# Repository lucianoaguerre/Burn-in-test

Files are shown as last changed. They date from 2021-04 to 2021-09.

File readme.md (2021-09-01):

# Proyecto

Burn-in Test

## Descripcion

En este documento se propone un sistema para hacer el burn-in test a fuentes de alimentación de tipo switching de 12V x 2A. El ensayo consiste en verificar que la fuente de alimentación esté funcionando correctamente, monitoreando la salida de 12V en vacío y en carga durante un lapso de tiempo. En dicho lapso la regulación de tensión no debe ser mayor que 10%, o el criterio que se elija. 

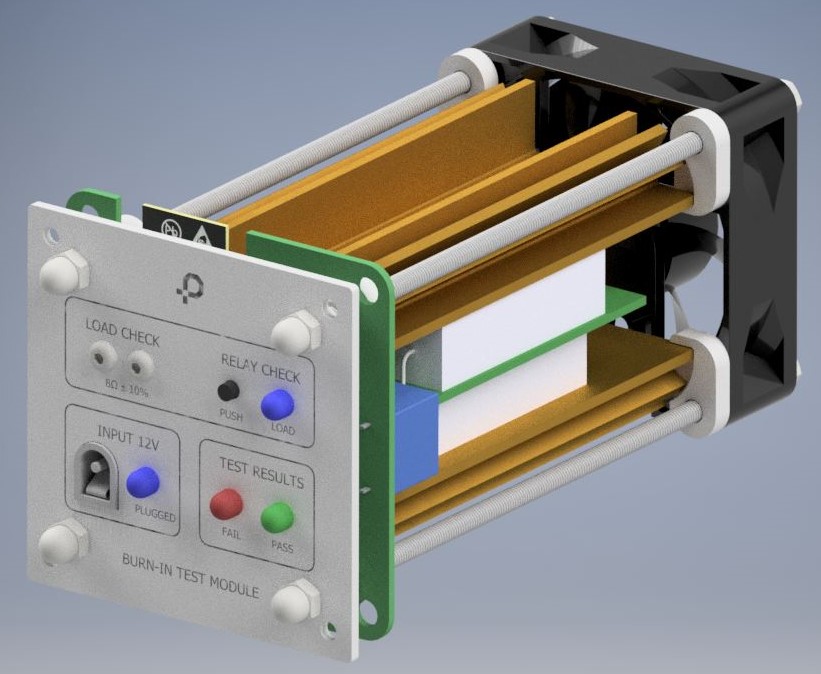
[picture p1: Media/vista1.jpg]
equipo

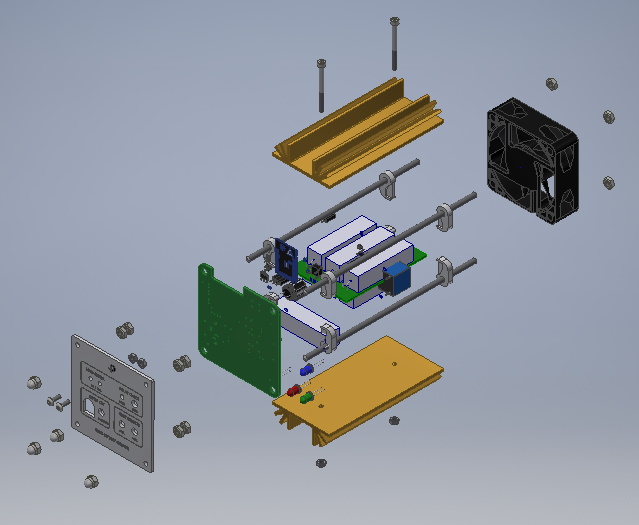
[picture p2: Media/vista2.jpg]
despiece


### Ciclado de la salida
Para estresar aún más las fuentes de alimentación que se están probando, la salida se enciende y apaga repetidamente. Si un dispositivo está destinado a fallar, generalmente pasa cuando la salida se cicla. Para capturar datos de falla, se mide la tensión de salida de cada fuente de alimentación cuando se enciende la salida. Después de que la salida se cicla de 15 a 20 veces, se deja encendida y se deja seguir envejeciendo la fuente. Mientras que la salida se deja encendida, el voltaje se mide solo ocasionalmente. 

### Ruido ambiente
Medir con exactitud la tensión de salida de una fuente switching es uy difícil en un contexto donde hay varias colocadas y funcionando al mismo tiempo, porque irradian ruido de alta frecuencia. Por lo tanto es importante que el circuito de medición realice promedios de cada muestra y tenga en cuento el efecto de sincronización de la medición de las fuentes.

### Vida útil de los componentes
Para hacer este test con carga, generalmente se utilizan relés, que conectan la resistencia con la salida de la fuente de alimentación. Pero como la fuente está encendida los relés se abren y cierran con voltaje en sus contactos. La activación de un relé de esta manera aumenta la posibilidad de formación de arco, lo que afecta la vida útil del mismo. Por otro lado, las resistencias cerámicas trabajan con una temperatura elevada, haciendo que irradien calor, debe monitorearse que la temperatura del módulo no sea muy elevada, para no reducir la vida útil de las mismas. Finalmente otro elemento que puede desgastarse es el conector de la fuente, de tanto colocar y retirar los enchufes puede dañarse las partes internas del conector y debe ser reemplazado.

### Corriente de carga
Si bien la fuente de alimentación a ensayar es de 2A, se propone que el ensayo con carga se haga al 80% de la corriente máxima, para no disipar tanto calor en los componentes.

### Ciclos
Para reducir el ruido eléctrico provocado por la transición de conexión y desconexión de las resistencias de carga, se propone un esquema de 12 ciclos de 5 segundos y luego se mantiene encendido con carga. El ciclo de la siguiente fuente comienza cuando termina la primera, y así sucesivamente. El ciclo completo de 10 fuentes es de 10 minutos. Por lo general, las recomendaciones para el test de burn-in sugieren probar las fuentes 4hs y si no hay fallas reducir el tiempo a 2hs. En el caso que ese tiempo sea muy largo se puede acortar o reducir los ciclos.

## Autor

Luciano Aguerre
[@luchoaguerre](https://twitter.com/luchoaguerre)

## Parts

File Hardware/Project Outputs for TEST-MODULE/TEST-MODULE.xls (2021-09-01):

Proveedor Electronica ELEMON
Presupuesto: 1204800 *** MODIFICAR CANTIDADES ***
Description | Designator | Quantity | COD. ELEMON | Cantidad | Precio | IVA | Total | IVA | Total + IVA
100NFX50V X7R 10% CER.MULT. SMD 0805 | C1, C2, C3, C5, C6 | 5 | CA3279774 | 700 | 0.01515 | 10.5% | 10.61 | 1.11 | 11.72
M7 DIODO 1A 1000V SMD-SMA (1N4007) XYG | D1 | 1 | DI1202221 | 200 | 0.01689 | 10.5% | 3.38 | 0.35 | 3.73
IDC-MA-THT-1X3-P2.54MM-L11 | P1 | 1 | CO4900906 | 15 | 0.22367 | 10.5% | 3.36 | 0.35 | 3.71
BC817-40 TRA.NPN 45V0.5A 0.25W SOT23 | Q1, Q3, Q4 | 3 | TR1723020 | 400 | 0.03377 | 10.5% | 13.51 | 1.42 | 14.93
33K 5% 0805 1/8W RES.SMD | R4 | 1 | RS3896275 | 5000 | 0.00224 | 10.5% | 11.20 | 1.18 | 12.38
5.6K 5% 0805 1/8W RES.SMD | R5 | 1 | RS3896230 | 5000 | 0.00224 | 10.5% | 11.20 | 1.18 | 12.38
1K 5% 0805 1/8W RES.SMD | R7 | 1 | RS3896185 | 5000 | 0.00224 | 10.5% | 11.20 | 1.18 | 12.38
220E 5% 0805 1/8W RES.SMD | R10, R12, R13, R14 | 4 | RS3896145 | 5000 | 0.00224 | 10.5% | 11.20 | 1.18 | 12.38
Relay simple inversor 12V 12A SRA-12VDC-CL | RELE | 1 | RE4551790 | 120 | 0.38998 | 21.0% | 46.80 | 9.83 | 56.63
TACT-SWITCH-THT-4C-06X06(5MM) | SW1 | 1 | SW5702101 | 120 | 0.08135 | 10.5% | 9.76 | 1.03 | 10.79
ESP32-WROOM-32E | U1 | 1 | RF9301435 | 120 | 4.48199 | 10.5% | 537.84 | 56.47 | 594.31
LD1117S33TR SMD DPAK 0.8A 3.3V LDO LINEAR REGULATOR | U2 | 1 | CI2707214DT | 120 | 0.12299 | 10.5% | 14.76 | 1.55 | 16.31
 |  |  |  |  |  |  | USD 684.80325 | USD 76.81808925 | USD 761.6213393
 |  |  |  |  |  |  | Tipo cambio BNA |  | 100.75
 |  |  |  |  |  |  |  | TOTAL | $76733.34993
Proveedor SYC-Semiconductores y Componentes
Presupuesto: 30355
Description | Designator | Quantity | COD. SYC | Cantidad | Precio | IVA | Total | IVA | Total + IVA
Transistor MOSFET N IRFD110 | Q2 | 1 | IRFD110 | 120 | 0.650 | 10.5% | 78.00 | 8.19 | 86.19
LED 5MM VERDE ALTO 9 | LD1 | 1 | LG3330 | 120 | 0.080 | 10.5% | 9.60 | 1.01 | 10.61
LED 5MM ROJO ALTO 9 | LD2 | 1 | LH3330 | 120 | 0.070 | 10.5% | 8.40 | 0.88 | 9.28
LED 5MM AZUL ALTO 9 | LD3, LD4 | 2 | LB3330 | 240 | 0.100 | 10.5% | 24.00 | 2.52 | 26.52
TACT-SWITCH-THT-4C-06X06(17MM) | SW2 | 1 | TS-6 | 30 | 0.170 | 10.5% | 5.10 | 0.54 | 5.64
10K 5% 0805 1/8W RES.SMD - pack por 100 | R1, R6, R8, R9, R11 | 5 | CR0850-10k | 6 | 0.500 | 10.5% | 3.00 | 0.32 | 3.31
 |  |  |  |  |  |  | USD 128.1 | USD 13.4505 | USD 141.5505
 |  |  |  |  |  |  | Tipo Cambio ICBC |  | 101.5
 |  |  |  |  |  |  |  | TOTAL | $14367.37575
Proveedor Microelectronica SH
Presupuesto: V 0001-00008601
Description | Designator | Quantity | COD. MicroelectronicaSH | Cantidad | Precio | IVA | Total | IVA | Total + IVA
DC POWER JACK VERTICAL 2MM | P3 | 1 | Jk-dc021-vert | 120 | 54.11 | 21.0% | 6492.96 | 1363.52 | 7856.48
100UFX16V 20%. 6.3x5.3 ELE.RAD.SMD [R=] | C4 | 1 | Ce100x16smd | 120 | 16.50 | 21.0% | 1980.00 | 415.80 | 2395.80
Resistencia Ceramica 330E 5% 10W SE15 RES.CEM | R2, R3 | 2 | RA-10W-330 | 240 | 50.79 | 21.0% | 12189.36 | 2559.77 | 14749.13
TACT-SWITCH-THT-4C-06X06(17MM) | SW2 | 1 | TS4-17 | 120 | 23.84 | 10.5% | 2860.80 | 300.38 | 3161.18
 |  |  |  |  |  |  | $23523.12 | $4639.4712 | $28162.5912
 |  |  |  |  |  |  |  | TOTAL | $28162.5912
Proveedor Ernesto Mayer
Presupuesto: 231456.1
Description | Designator | Quantity |  | Cantidad | Precio | IVA | Total | IVA | Total + IVA
Test Module |  | 120 |  | 120 | 5.79 | 10.5% | 694.80 | 72.95 | 767.75
Gasto de prefabricacion |  | 1 |  | 1 | 30.00 | 21.0% | 30.00 | 6.30 | 36.30
 |  |  |  |  |  |  | USD 724.8 | USD 79.254 | USD 804.054
 |  |  |  |  |  |  | Tipo cambio BNA |  | 101.25
 |  |  |  |  |  |  |  | TOTAL | $81410.4675
Proveedor Abul Tornillos
Presupuesto:
Description | Designator | Quantity |  | Cantidad | Precio | IVA | Total | IVA | Total + IVA
TORNILLO ISO 7380-1 - M3x16 |  | 4 |  | 504 | 15.00 | 21.0% | 7560.00 | 1587.60 | 9147.60
TUERCA DIN 934 M3x0.5 |  | 4 |  | 504 | 4.00 | 21.0% | 2016.00 | 423.36 | 2439.36
 |  |  |  |  |  |  | $9576 | $2010.96 | $11586.96
 |  |  |  |  |  |  |  | TOTAL | $11586.96
Proveedor Wabe 3D
Presupuesto:
Description | Designator | Quantity |  | Cantidad | Precio | IVA | Total | IVA | Total + IVA
Frente |  | 4 |  | 504 | 15.00 | 21.0% | 7560.00 | 1587.60 | 9147.60
Separador para placa |  | 4 |  | 504 | 10.00 | 21.0% | 5040.00 | 1058.40 | 6098.40
Separador para LED |  | 4 |  | 504 | 10.00 | 21.0% | 5040.00 | 1058.40 | 6098.40
 |  |  |  |  |  |  | $17640 | $3704.4 | $21344.4
 |  |  |  |  |  |  |  | TOTAL | $21344.4
 |  |  |  |  |  |  |  | Total | $233605.1444

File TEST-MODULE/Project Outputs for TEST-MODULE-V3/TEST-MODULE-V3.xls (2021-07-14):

Description | Designator | Quantity | COD. ELEMON | Total
100NFX50V X7R 10% CER.MULT. SMD 0805 | C1, C2, C3, C5, C6 | 5 | CA3279774 | 600
470UFX25V 85°C 10x13 ELE.RAD | C4 | 1 | CA3609281A | 120
Diodo 1N4007 DIODO 1A 1000V DO41 | D1 | 1 | DI1152060 | 120
IDC-HE-THT-1X4-P2.54MM | P1 | 1 | CO5001085 | 120
IDC-MA-THT-1X2-P2.54MM-L11 | P2 | 1 | CO496C20 | 120
BC817-40 TRA.NPN 45V0.5A 0.25W SOT23 | Q2, Q3, Q4 | 3 | TR1723020 | 360
10K 5% 0805 1/8W RES.SMD | R1, R6, R8, R13, R16 | 5 | RS3896245 | 600
220E 5% 0805 1/8W RES.SMD | R3, R4, R5, R7 | 4 | RS3896145 | 480
33K 5% 0805 1/8W RES.SMD | R9 | 1 | RS3896275 | 120
5.6K 5% 0805 1/8W RES.SMD | R10 | 1 | RS3896230 | 120
Resistencia Ceramica 330E 5% 10W SE15 RES.CEM | R11, R12 | 2 | RS4096155 | 240
1K 5% 0805 1/8W RES.SMD | R14 | 1 | RS3896185 | 120
Relay simple inversor 12V 12A | RELE1 | 1 | RE4551790 | 120
TACT-SWITCH-THT-4C-06X06(13MM)-JIANFU | SW1 | 1 | SW5702124 | 120
TACT-SWITCH-THT-4C-06X06(5MM) | SW2 | 1 | SW5702101 | 120
ESP32-WROOM-32D | U1 | 1 | RF9301435 | 120
LD1117S33TR SMD DPAK 0.8A 3.3V LDO LINEAR REGULATOR | U2 | 1 | CI2707214DT | 120
LED 5MM AZUL ALTO 9 | LD1, LD4 | 2 |  | 240
LED 5MM VERDE ALTO 9 | LD2 | 1 |  | 120
LED 5MM ROJO ALTO 9 | LD3 | 1 |  | 120
DC POWER JACK VERTICAL 2MM | P4 | 1 |  | 120
Transistor MOSFET N IRFD110 | Q1 | 1 |  | 120

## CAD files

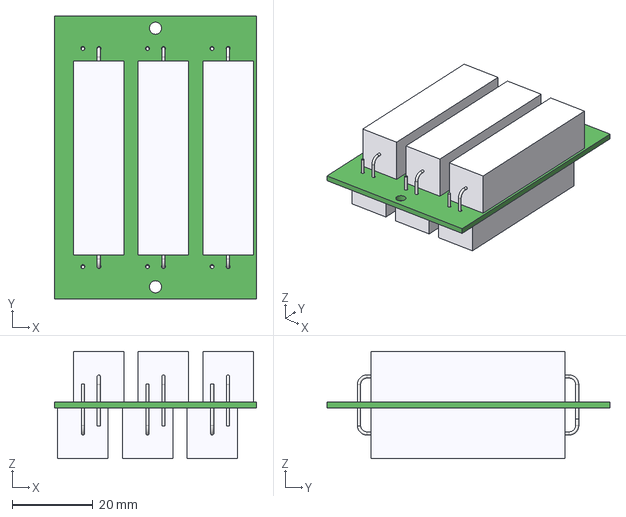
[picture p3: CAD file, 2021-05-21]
TEST-MODULE/3D/RESISTOR-BOARD/RESISTORS-BOARD.step
50.0 x 70.0 x 26.6 mm
Board
AXIAL-POWER x 6

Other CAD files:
Hardware/3D/AXIAL-POWER-10W.ipt
Hardware/3D/Board.ipt
Hardware/3D/C1.iam
Hardware/3D/C2.iam
Hardware/3D/C3.iam
Hardware/3D/C4.iam
Hardware/3D/C5.iam
Hardware/3D/C6.iam
Hardware/3D/CAP-ELEC-SMD-100UF.ipt
Hardware/3D/CAP-SMD-0805.iam
Hardware/3D/CON-PIN-CORTO.ipt
Hardware/3D/D1.iam
Hardware/3D/DC-JACK-VERT.ipt
Hardware/3D/DPAK.iam
Hardware/3D/Diode_SMA.ipt
Hardware/3D/LD1.iam
Hardware/3D/LD2.iam
Hardware/3D/LD3.iam
Hardware/3D/LD4.iam
Hardware/3D/LED_5MM_BLUE_9.ipt
Hardware/3D/LED_5MM_GREEN_9.ipt
Hardware/3D/LED_5MM_RED_9.ipt
Hardware/3D/OldVersions/TEST-MODULE.0001.iam
Hardware/3D/Open CASCADE STEP translator 6.8 4.2.1.1.ipt
Hardware/3D/Open CASCADE STEP translator 6.8 4.2.1.2.ipt
Hardware/3D/Open CASCADE STEP translator 6.8 4.2.1.3.ipt
Hardware/3D/Open CASCADE STEP translator 6.8 4.2.1.4.ipt
Hardware/3D/Open CASCADE STEP translator 6.8 4.38.1.1.ipt
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

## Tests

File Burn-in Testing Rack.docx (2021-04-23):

Burn-in Testing

Introducción

En este documento se propone un sistema para hacer el burn-in test a fuentes de alimentación de tipo switching de 12V x 2A. El ensayo consiste en verificar que la fuente de alimentación esté funcionando correctamente, monitoreando la salida de 12V en vacío y en carga durante un lapso de tiempo. En dicho lapso la regulación de tensión no debe ser mayor que 10%, o el criterio que se elija.

Monitoreo de Tensión

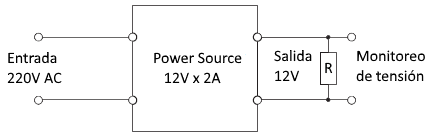
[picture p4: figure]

La figura 1 es un esquema simple de una prueba para monitorear la salida de tensión de una fuente de alimentación. Un sistema de conversión analógico digital se conectaría en paralelo con la resistencia de carga para medir el voltaje de la fuente de alimentación.

Figura 1. Monitoreo de tensión

El valor de la resistencia de carga se elige simulando la carga encontrada en la aplicación final, pero también puede elegirse para alcanzar la máxima capacidad de salida haciendo una prueba de esfuerzo de la fuente.

Ciclado de la salida

Para estresar aún más las fuentes de alimentación que se están probando, la salida se enciende y apaga repetidamente. Si un dispositivo está destinado a fallar, generalmente pasa cuando la salida se cicla. Para capturar datos de falla, se mide la tensión de salida de cada fuente de alimentación cuando se enciende la salida, como se muestra en la Figura 2. Después de que la salida se cicla de 15 a 20 veces, se deja encendida y se deja seguir envejeciendo la fuente. Mientras que la salida se deja encendida, el voltaje se mide solo ocasionalmente.

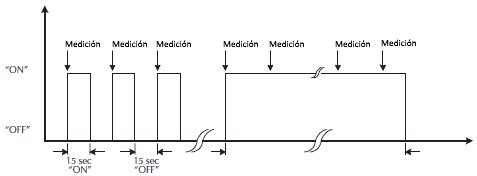
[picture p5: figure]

Figura 2. Ciclo típico de burn-in test.

Ruido ambiente

Medir con exactitud la tensión de salida de una fuente switching es uy difícil en un contexto donde hay varias colocadas y funcionando al mismo tiempo, porque irradian ruido de alta frecuencia. Por lo tanto es importante que el circuito de medición realice promedios de cada muestra y tenga en cuento el efecto de sincronización de la medición de las fuentes.

Vida útil de los componentes

Para hacer este test con carga, generalmente se utilizan relés, que conectan la resistencia con la salida de la fuente de alimentación. Pero como la fuente está encendida los relés se abren y cierran con voltaje en sus contactos. La activación de un relé de esta manera aumenta la posibilidad de formación de arco, lo que afecta la vida útil del mismo. Por otro lado, las resistencias cerámicas trabajan con una temperatura elevada, haciendo que irradien calor, debe monitorearse que la temperatura del módulo no sea muy elevada, para no reducir la vida útil de las mismas. Finalmente otro elemento que puede desgastarse es el conector de la fuente, de tanto colocar y retirar los enchufes puede dañarse las partes internas del conector y debe ser reemplazado.

Corriente de carga

Si bien la fuente de alimentación a ensayar es de 2A, se propone que el ensayo con carga se haga al 80% de la corriente máxima, para no disipar tanto calor en los componentes.

Implementación del sistema

Módulos

Dadas las consideraciones expuestas anteriormente se propone que el sistema de medición, ilustrado en la figura 3, conste de un módulo central, donde están los procesadores con los conversores AD, y de 10 módulos de carga donde están los componentes que pueden fallar. Todos interconectados con cables para que sea sencillo el reemplazo de un módulo por otro, en el caso de que un componente falle.

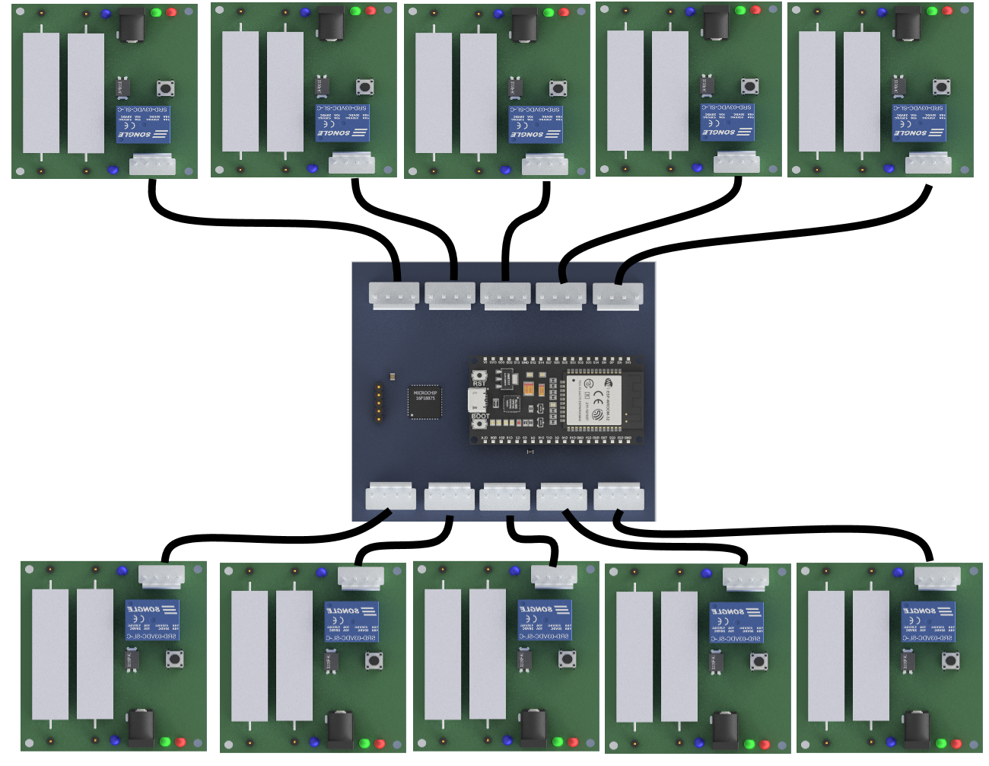
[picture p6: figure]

Figura 3. Ilustración de sistema de medición

Ciclos

Para reducir el ruido eléctrico provocado por la transición de conexión y desconexión de las resistencias de carga, se propone un esquema de 12 ciclos de 5 segundos y luego se mantiene encendido con carga. El ciclo de la siguiente fuente comienza cuando termina la primera, y así sucesivamente. El ciclo completo de 10 fuentes es de 10 minutos. Por lo general, las recomendaciones para el test de burn-in sugieren probar las fuentes 4hs y si no hay fallas reducir el tiempo a 2hs. En el caso que ese tiempo sea muy largo se puede acortar o reducir los ciclos.

Figura 4. Esquema de ciclos de carga

Detalle módulo de carga

En la figura 5 se ve con más detalle las partes que componen el módulo de carga. El circuito está compuesto por el Jack Power donde se conecta la fuente de alimentación a ensayar, a la izquierda está los dos LEDs indicadores de aceptado o rechazado. En la parte inferior están las dos resistencias de carga de 15 ohm x 15W, que toman 1.6A de la fuente, es decir el 80% de la máxima como se había propuesto. El LED azul de la izquierda es un testigo de que la fuente está enchufada correctamente, y el LED azul de la derecha es un testigo de que hay tensión después del relé. A ambos lados de las resistencias hay pines de prueba, para verificar que después de un periodo de tiempo mantiene su valor nominal. El pulsador provoca un disparo del relé, con el fin de verificar que el mismo funcione correctamente.

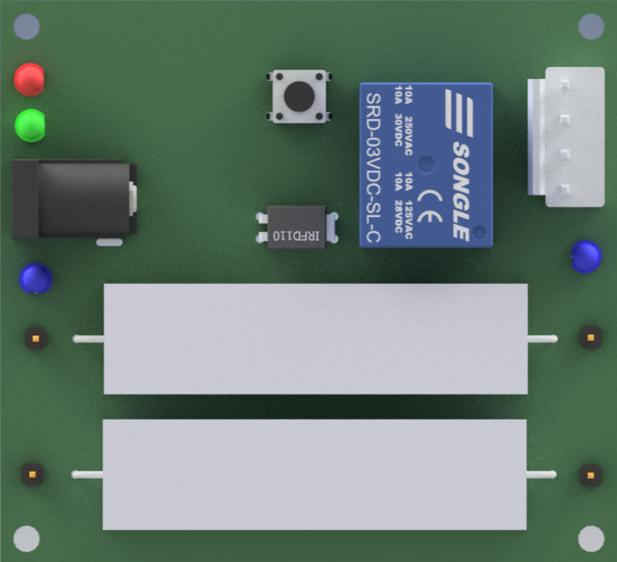
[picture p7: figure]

Figura 5. Módulo de carga

Antes de empezar con los ensayos a un lote fuentes se debe medir con un multímetro que los valores de las resistencias estén dentro los parámetros admisibles, para ello se conectan las puntas en los pines dispuestos para tal ensayo, el valor medido debería ser 7,5 ohms con una tolerancia del 20%. Del mismo modo, debe procederse al finalizar la jornada. También se debe verificar que el relé no se haya dañado, para ello se puede utilizar el pulsador dispuesto en la placa, que energiza al relé haciendo que pase tensión a las resistencias. En este caso debe encenderse el LED azul dispuesto cerca del conector de datos.

Detalle módulo central

En la figura 6 se ve con más detalle las partes que componen el módulo central. El circuito está compuesto por un sub módulo de alimentación de 12V, el microcontrolador central PIC16F18875 que es el responsable de la toma de datos y el procesamiento de las señales, y un módulo ESP32, que va alojar un pequeño web server para que los datos puedan ser tomados de forma remota y por último los conectores para los módulos de carga.

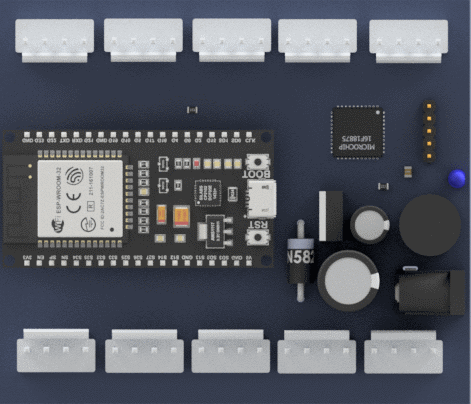
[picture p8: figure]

Figura 6. Módulo central

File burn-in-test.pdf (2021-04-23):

# Burn-in Testing

## Introducción

En este documento se propone un sistema para hacer el burn-in test a fuentes de alimentación de tipo switching de 12V x 2A. El ensayo consiste en verificar que la fuente de alimentación esté funcionando correctamente, monitoreando la salida de 12V en vacío y en carga durante un lapso de tiempo. En dicho lapso la regulación de tensión no debe ser mayor que 10%, o el criterio que se elija.

Monitoreo de Tensión
La figura 1 es un esquema simple de una prueba para monitorear la salida de tensión de una fuente de alimentación. Un sistema de conversión analógico digital se conectaría en paralelo con la resistencia de carga para medir el voltaje de la fuente de alimentación.

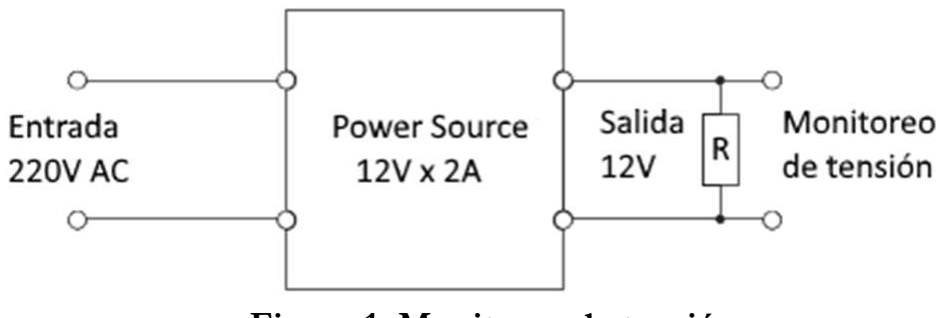
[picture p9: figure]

Figura 1. Monitoreo de tensión
El valor de la resistencia de carga se elige simulando la carga encontrada en la aplicación final, pero también puede elegirse para alcanzar la máxima capacidad de salida haciendo una prueba de esfuerzo de la fuente.

Ciclado de la salida
Para estresar aún más las fuentes de alimentación que se están probando, la salida se enciende y apaga repetidamente. Si un dispositivo está destinado a fallar, generalmente pasa cuando la salida se cicla. Para capturar datos de falla, se mide la tensión de salida de cada fuente de alimentación cuando se enciende la salida, como se muestra en la Figura 2. Después de que la salida se cicla de 15 a 20 veces, se deja encendida y se deja seguir envejeciendo la fuente. Mientras que la salida se deja encendida, el voltaje se mide solo ocasionalmente.

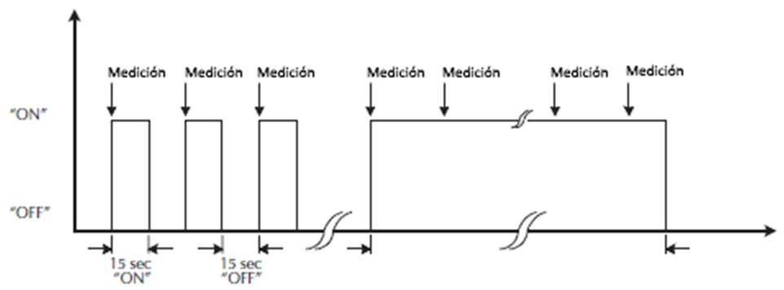
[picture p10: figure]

Figura 2. Ciclo típico de burn-in test.

Ruido ambiente
Medir con exactitud la tensión de salida de una fuente switching es uy difícil en un contexto donde hay varias colocadas y funcionando al mismo tiempo, porque irradian ruido de alta frecuencia. Por lo tanto es importante que el circuito de medición realice promedios de cada muestra y tenga en cuento el efecto de sincronización de la medición de las fuentes.

Vida útil de los componentes
Para hacer este test con carga, generalmente se utilizan relés, que conectan la resistencia con la salida de la fuente de alimentación. Pero como la fuente está encendida los relés se abren y cierran con voltaje en sus contactos. La activación de un relé de esta manera aumenta la posibilidad de formación de arco, lo que afecta la vida útil del mismo. Por otro lado, las resistencias cerámicas trabajan con una temperatura elevada, haciendo que irradien calor, debe monitorearse que la temperatura del módulo no sea muy elevada, para no reducir la vida útil de las mismas. Finalmente otro elemento que puede desgastarse es el conector de la fuente, de tanto colocar y retirar los enchufes puede dañarse las partes internas del conector y debe ser reemplazado.

Corriente de carga
Si bien la fuente de alimentación a ensayar es de 2A, se propone que el ensayo con carga se haga al 80% de la corriente máxima, para no disipar tanto calor en los componentes.

## Implementación del sistema

Módulos
Dadas las consideraciones expuestas anteriormente se propone que el sistema de medición, ilustrado en la figura 3, conste de un módulo central, donde están los procesadores con los conversores AD, y de 10 módulos de carga donde están los componentes que pueden fallar. Todos interconectados con cables para que sea sencillo el reemplazo de un módulo por otro, en el caso de que un componente falle.

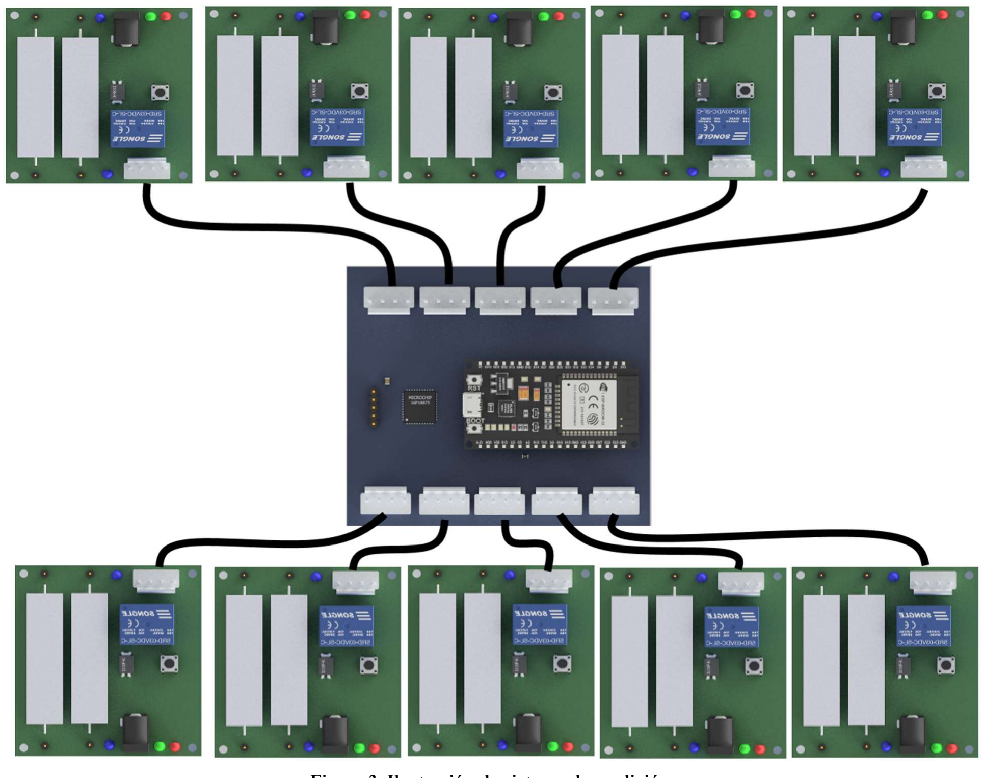
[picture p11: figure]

Figura 3. Ilustración de sistema de medición

Ciclos
Para reducir el ruido eléctrico provocado por la transición de conexión y desconexión de las resistencias de carga, se propone un esquema de 12 ciclos de 5 segundos y luego se mantiene encendido con carga. El ciclo de la siguiente fuente comienza cuando termina la primera, y así sucesivamente. El ciclo completo de 10 fuentes es de 10 minutos. Por lo general, las recomendaciones para el test de burn-in sugieren probar las fuentes 4hs y si no hay fallas reducir el tiempo a 2hs. En el caso que ese tiempo sea muy largo se puede acortar o reducir los ciclos.

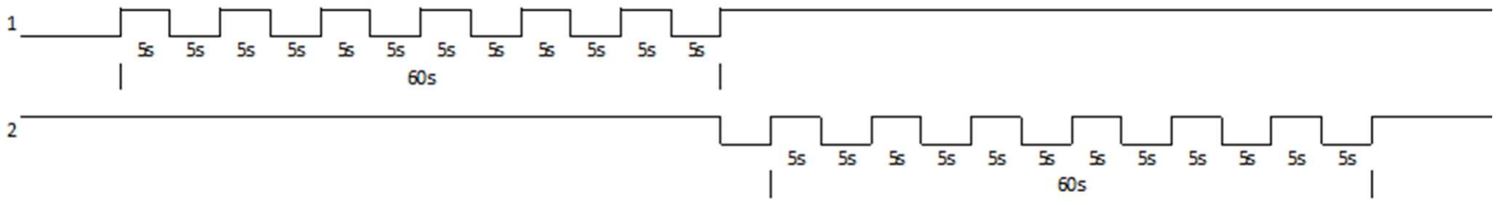
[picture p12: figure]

Figura 4. Esquema de ciclos de carga

Detalle módulo de carga
En la figura 5 se ve con más detalle las partes que componen el módulo de carga. El circuito está compuesto por el Jack Power donde se conecta la fuente de alimentación a ensayar, a la izquierda está los dos LEDs indicadores de aceptado o rechazado. En la parte inferior están las dos resistencias de carga de 15 ohm x 15W, que toman 1.6A de la fuente, es decir el 80% de la máxima como se había propuesto. El LED azul de la izquierda es un testigo de que la fuente está enchufada correctamente, y el LED azul de la derecha es un testigo de que hay tensión después del relé. A ambos lados de las resistencias hay pines de prueba, para verificar que después de un periodo de tiempo mantiene su valor nominal. El pulsador provoca un disparo del relé, con el fin de verificar que el mismo funcione correctamente.

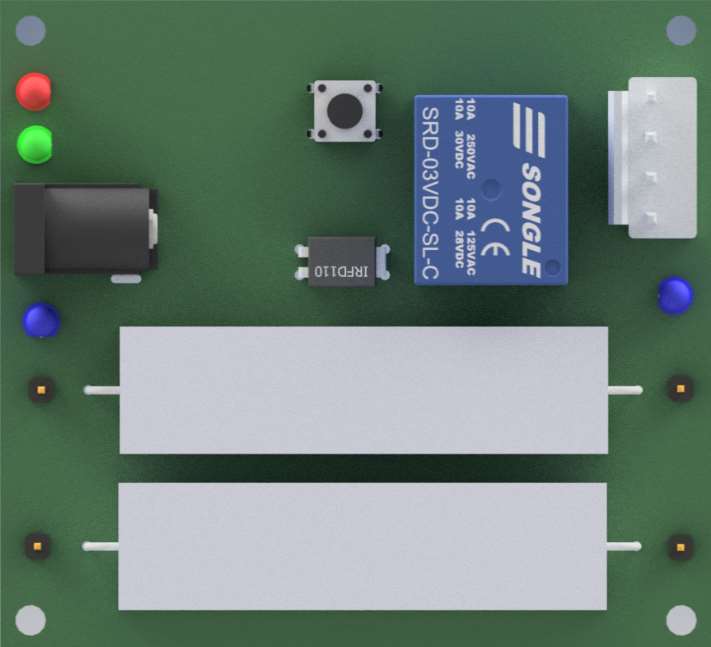
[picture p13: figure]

Figura 5. Módulo de carga

Antes de empezar con los ensayos a un lote fuentes se debe medir con un multímetro que los valores de las resistencias estén dentro los parámetros admisibles, para ello se conectan las puntas en los pines dispuestos para tal ensayo, el valor medido debería ser 7,5 ohms con una tolerancia del 20%. Del mismo modo, debe procederse al finalizar la jornada. También se debe verificar que el relé no se haya dañado, para ello se puede utilizar el pulsador dispuesto en la placa, que energiza al relé haciendo que pase tensión a las resistencias. En este caso debe encenderse el LED azul dispuesto cerca del conector de datos.

Detalle módulo central
En la figura 6 se ve con más detalle las partes que componen el módulo central. El circuito está compuesto por un sub módulo de alimentación de 12V, el microcontrolador central PIC16F18875 que es el responsable de la toma de datos y el procesamiento de las señales, y un módulo ESP32, que va alojar un pequeño web server para que los datos puedan ser tomados de forma remota y por último los conectores para los módulos de carga.


Figura 6. Módulo central

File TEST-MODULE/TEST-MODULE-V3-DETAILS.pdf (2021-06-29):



Comment | Description | Designator | Footprint | LibRef | Quantity | COD. ELEMON | COD. SYC
100NFX50V | 100NFX50V X7R 10% CER.MULT. SMD 0805 | C1, C2, C3, C5, C6 | CAP.SMD.0805 | Capacitor 100NFX50V X7R 10% CER.MULT. SMD 0805 | 5 | CA3279774

470UFX25V | 470UFX25V 85°C 10x13 ELE.RAD | C4 | CAP-ELEC-10X13 | Capacitor Electrolitico 470UFX25V 85°C 10x13 ELE.RAD | 1 | CA3609281A

1N4007 | Diodo 1N4007 DIODO 1A 1000V DO41 | D1 | Diode DO41 | Diodo 1N4007 DIODO 1A 1000V DO41 | 1 | DI1152060

LED 5MM AZUL | LED 5MM AZUL ALTO 9 | LD1, LD4 | LED-5MM-ALTO-9-AZUL | LED 5MM AZUL ALTO 9 | 2

LED 5MM VERDE | LED 5MM VERDE ALTO 9 | LD2 | LED-5MM-ALTO-9-VERDE | LED 5MM VERDE ALTO 9 | 1

LED 5MM ROJO | LED 5MM ROJO ALTO 9 | LD3 | LED-5MM-ALTO-9-ROJO | LED 5MM ROJO ALTO 9 | 1

IDC-HE-THT-1X4-P2.54MM | IDC-HE-THT-1X4-P2.54MM | P1 | IDC-HE-THT-1X4-P2.54MM | IDC-HE-THT-1X4-P2.54MM | 1 | CO5001085 | PB04S

IDC-MA-THT-1X2-P2.54MM-L11 | IDC-MA-THT-1X2-P2.54MM-L11 | P2 | IDC-MA-THT-1X2-P2.54MM-L11 | IDC-MA-THT-1X2-P2.54MM-L11 | 1 | CO496C20

DC POWER JACK | DC POWER JACK VERTICAL 2MM | P4 | VAR-DC-JACK -VERT | DC POWER JACK VERTICAL 2MM | 1

IRFD110 | Transistor MOSFET N IRFD110 | Q1 | TRA-IRFD110 | Transistor MOSFET N IRFD110 | 1

BC817 | BC817-40 TRA.NPN 45V0.5A 0.25W SOT23 | Q2, Q3, Q4 | NPN.SMD.SOT23 | Transistor BC817-40 TRA.NPN 45V0.5A 0.25W SOT23 | 3 | TR1723020

10K | 10K 5% 0805 1/8W RES.SMD | R1, R6, R8, R13, R16 | RES.SMD.103 | Resistencia 10K 5% 0805 1/8W | 5 | RS3896245

220E | 220E 5% 0805 1/8W RES.SMD | R3, R5, R7 | RES.SMD.221 | Resistencia 220E 5% 0805 1/8W | 3 | RS3896145

220E 5% | 220E 5% 0805 1/8W RES.SMD | R4 | RES.SMD.221 | Resistencia 220E 5% 0805 1/8W | 1 | RS3896145

33K | 33K 5% 0805 1/8W RES.SMD | R9 | RES.SMD.333 | Resistencia 33K 5% 0805 1/8W | 1 | RS3896275

5.6K | 5.6K 5% 0805 1/8W RES.SMD | R10 | RES.SMD.562 | Resistencia 5.6K 5% 0805 1/8W | 1 | RS3896230

330E 5% 10W | Resistencia Ceramica 330E 5% 10W SE15 RES.CEM | R11, R12 | RES-CERAMICA-10W | Resistencia Ceramica 330E 5% 10W SE15 RES.CEM | 2 | RS4096155

1K | 1K 5% 0805 1/8W RES.SMD | R14 | RES.SMD.102 | Resistencia 1K 5% 0805 1/8W | 1 | RS3896185

Relay simple inversor 12V 12A | Relay simple inversor 12V 12A | RELE1 | RELAY 12V 12A CHICO | VAR-RELE-12V Relay simple inversor chico 12V 12A | 1

TACT-SWITCH-THT-4C-06X06(13MM)-JIANFU | TACT-SWITCH-THT-4C-06X06(13MM)-JIANFU | SW1 | TACT-SWITCH-THT-4C-06X06-13MM | TACT-SWITCH-THT-4C-06X06(13MM)-JIANFU | 1 | SW5702124

TACT-SWITCH-THT-4C-06X06(5MM) | TACT-SWITCH-THT-4C-06X06(5MM) | SW2 | TACT-SWITCH-THT-4C-06X06-5MM | TACT-SWITCH-THT-4C-06X06(5MM) | 1 | SW5702101

ESP32-WROOM-32D | ESP32-WROOM-32D | U1 | ESP32-WROOM-32D | ESP32-WROOM-32D | 1 | RF9301435

LD1117S33TR SMD DPAK 0.8A 3.3V LDO LINEAR REGULATOR | LD1117S33TR SMD DPAK 0.8A 3.3V LDO LINEAR REGULATOR | U2 | DPAK | LD1117S33TR SMD DPAK 0.8A 3.3V LDO LINEAR REGULATOR | 1

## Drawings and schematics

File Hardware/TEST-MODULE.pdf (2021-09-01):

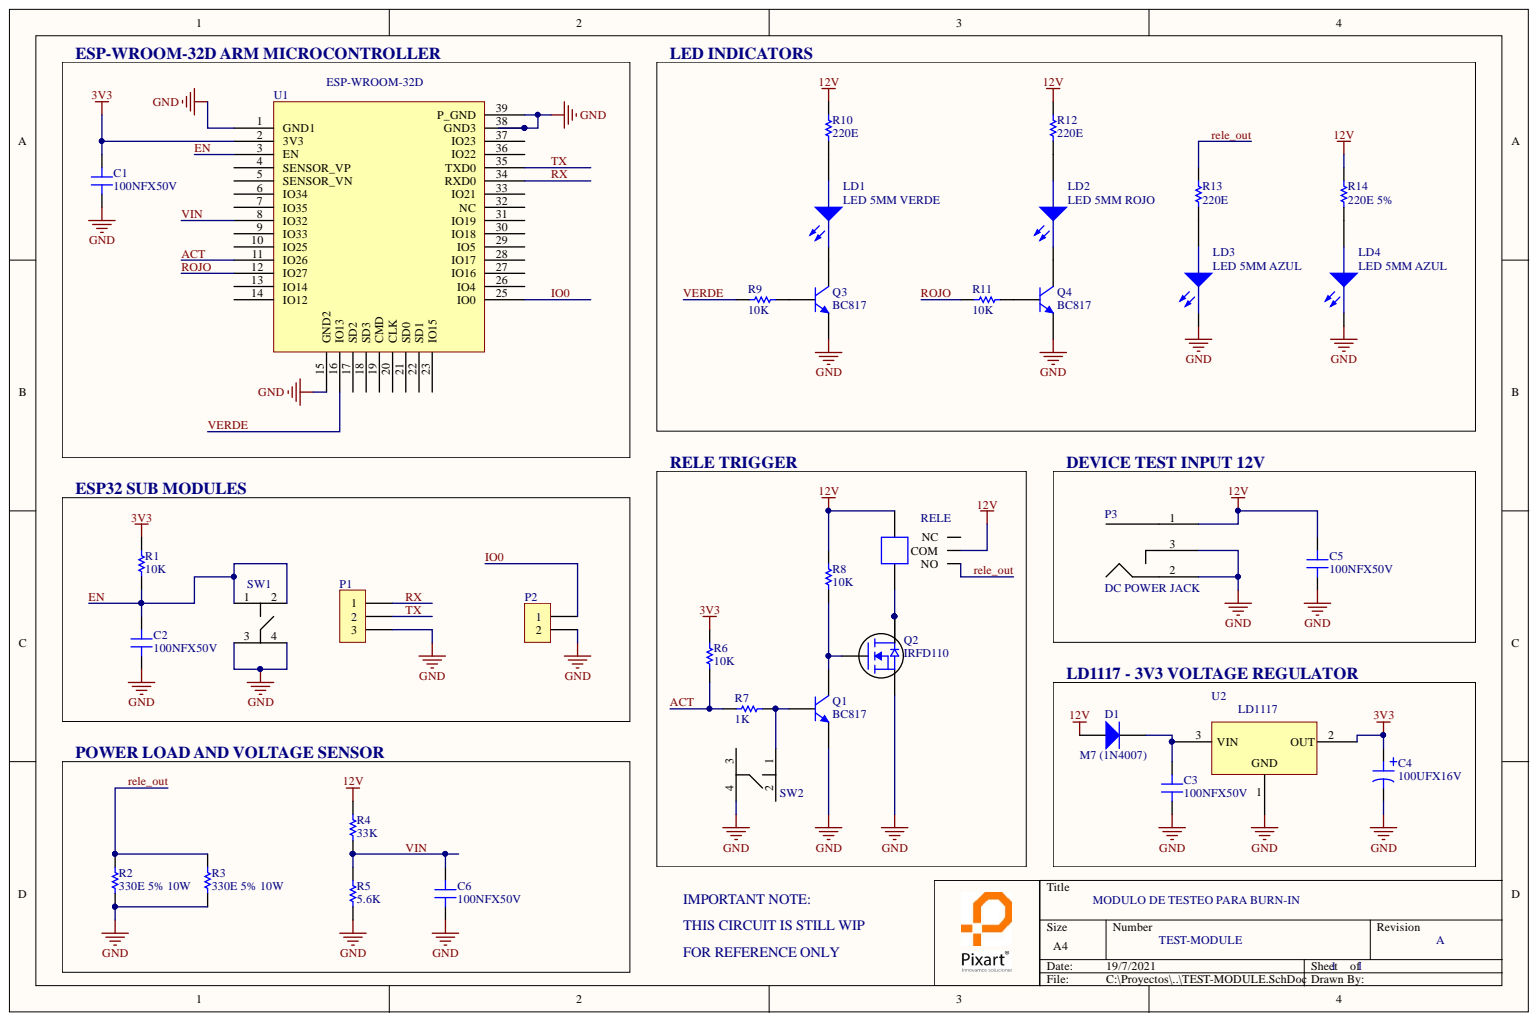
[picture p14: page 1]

THIS CIRCUIT IS STILL WIP FOR REFERENCE ONLY

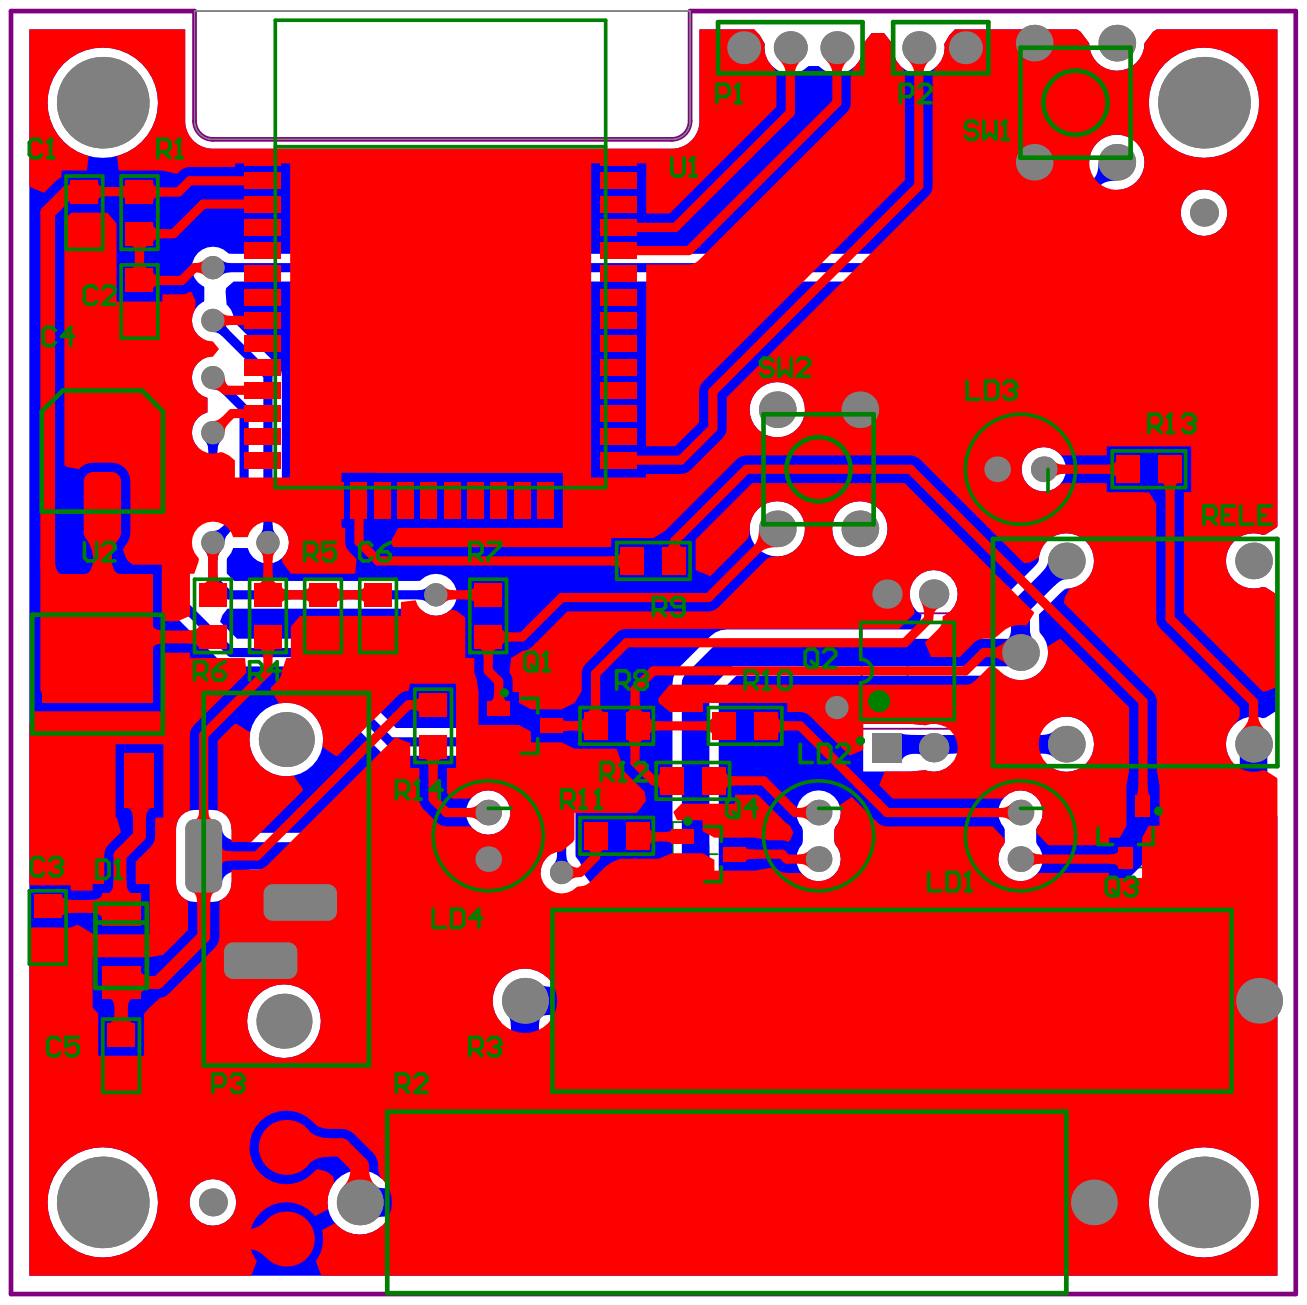
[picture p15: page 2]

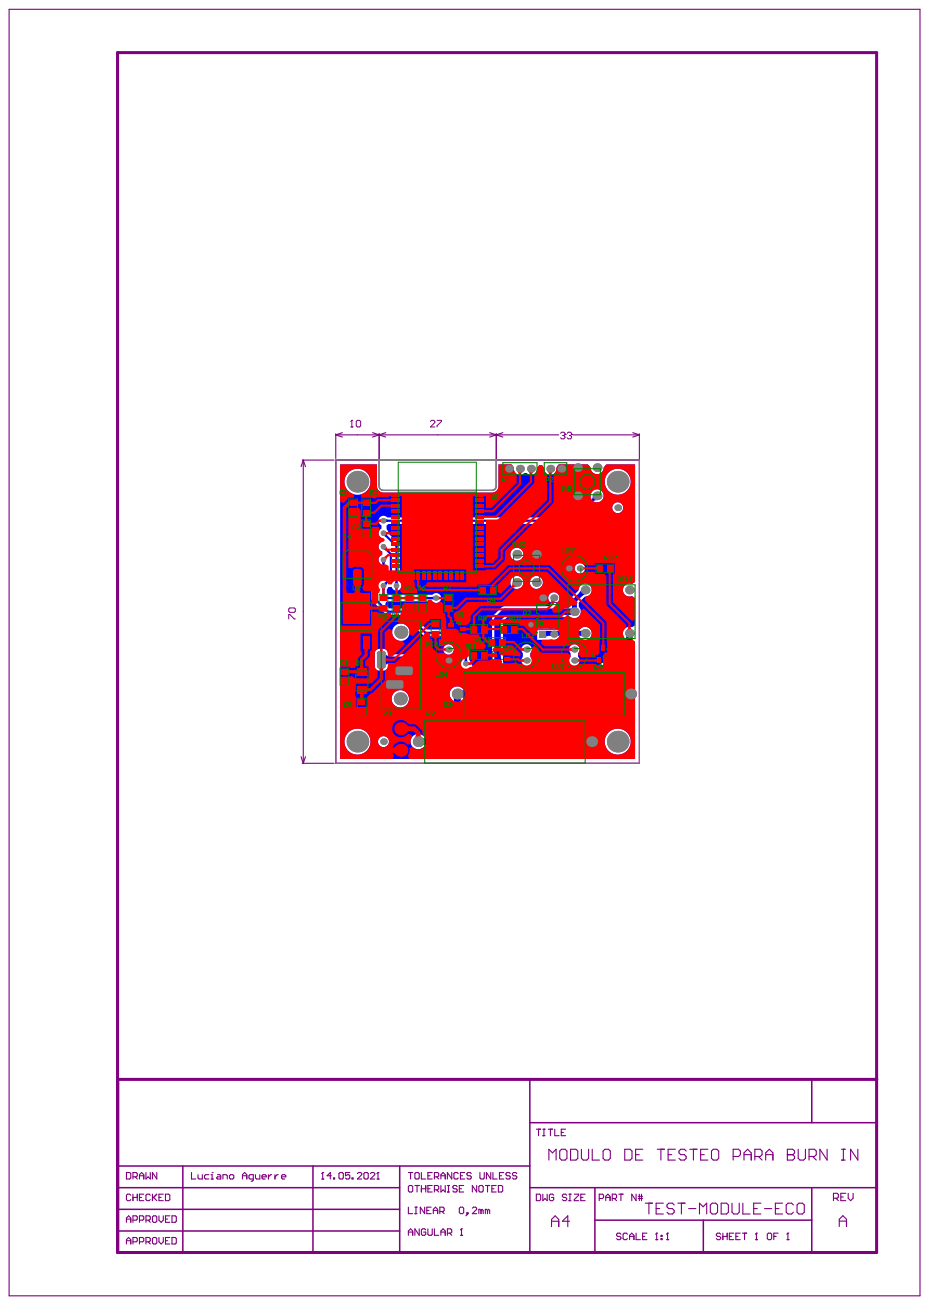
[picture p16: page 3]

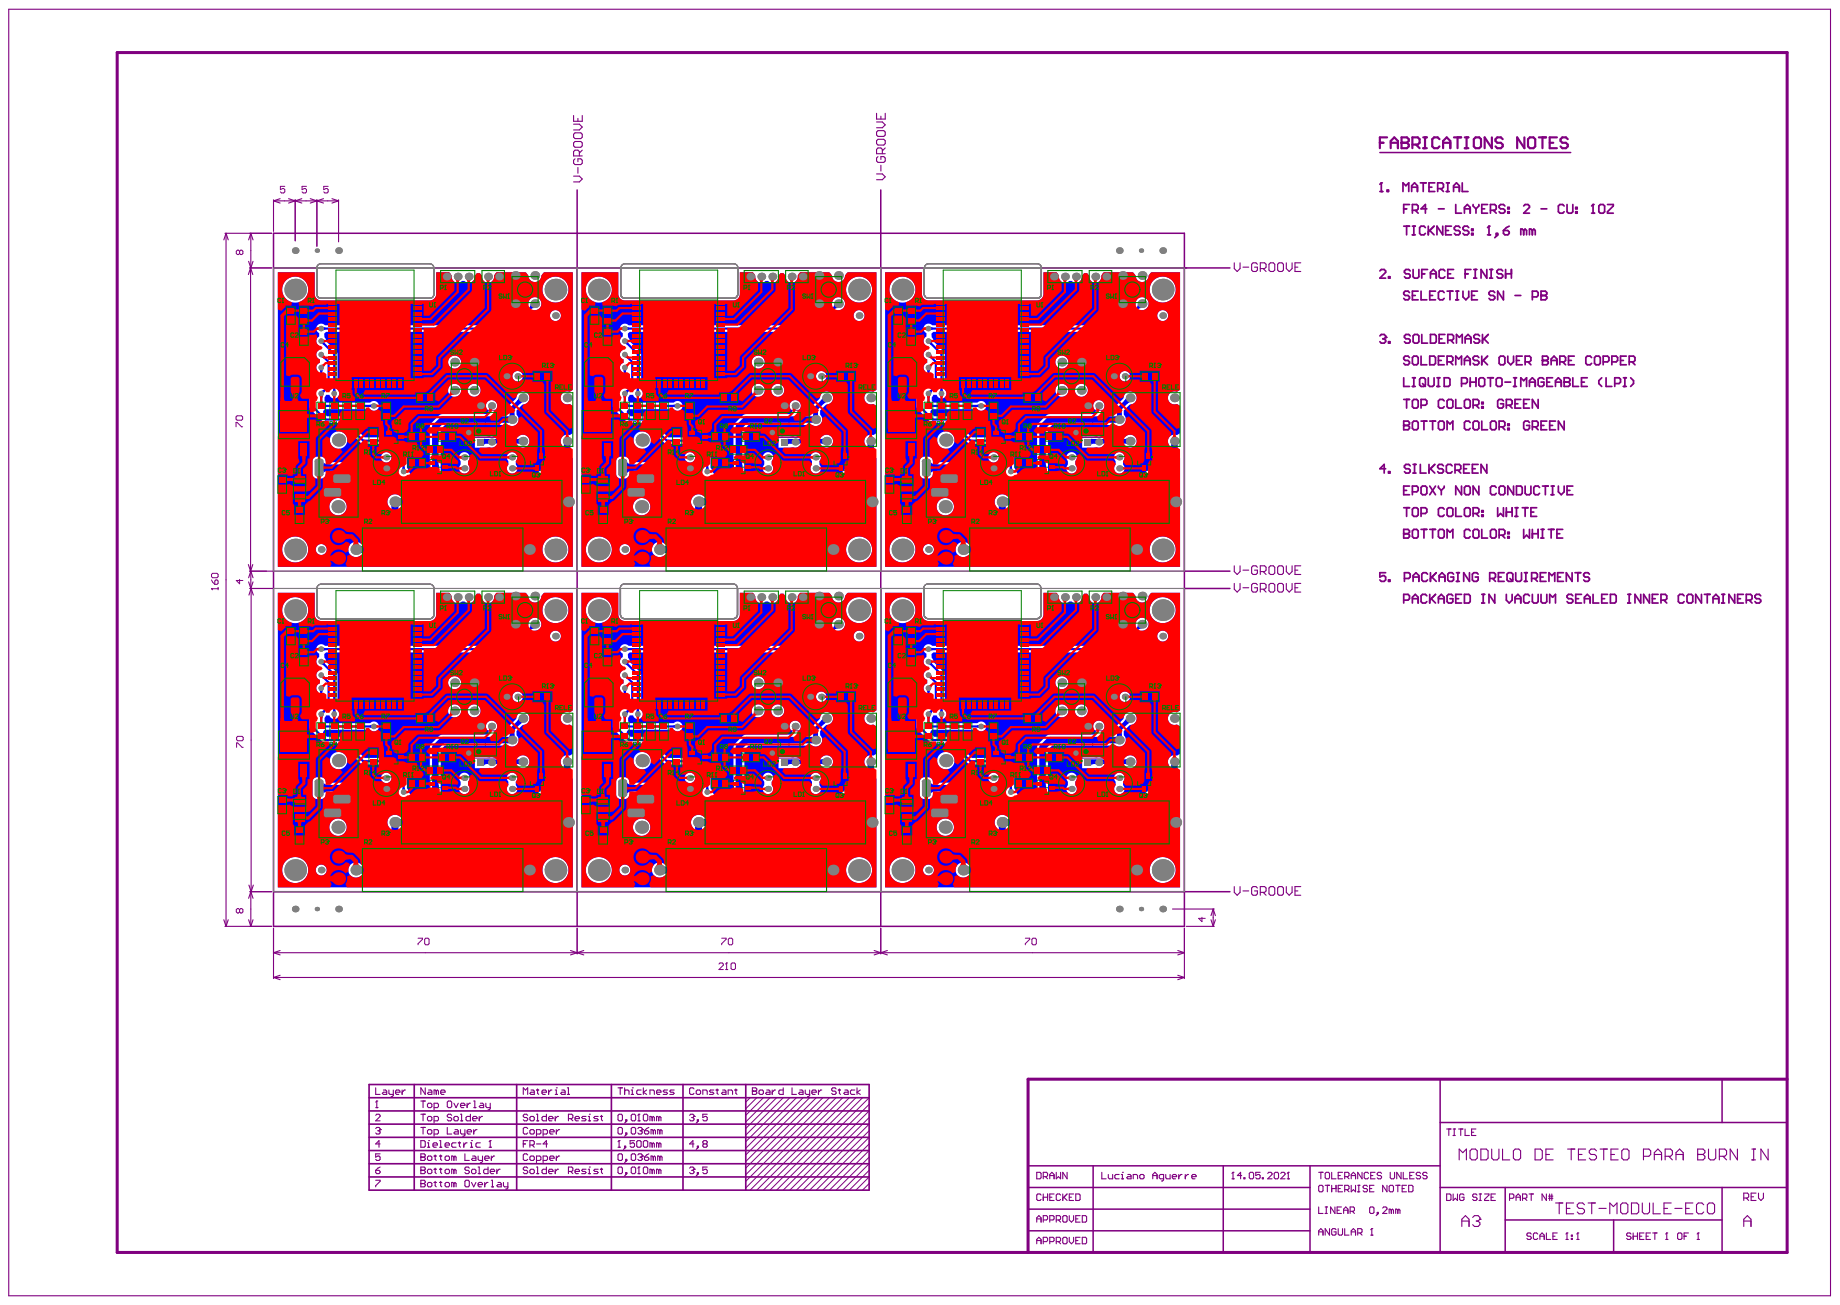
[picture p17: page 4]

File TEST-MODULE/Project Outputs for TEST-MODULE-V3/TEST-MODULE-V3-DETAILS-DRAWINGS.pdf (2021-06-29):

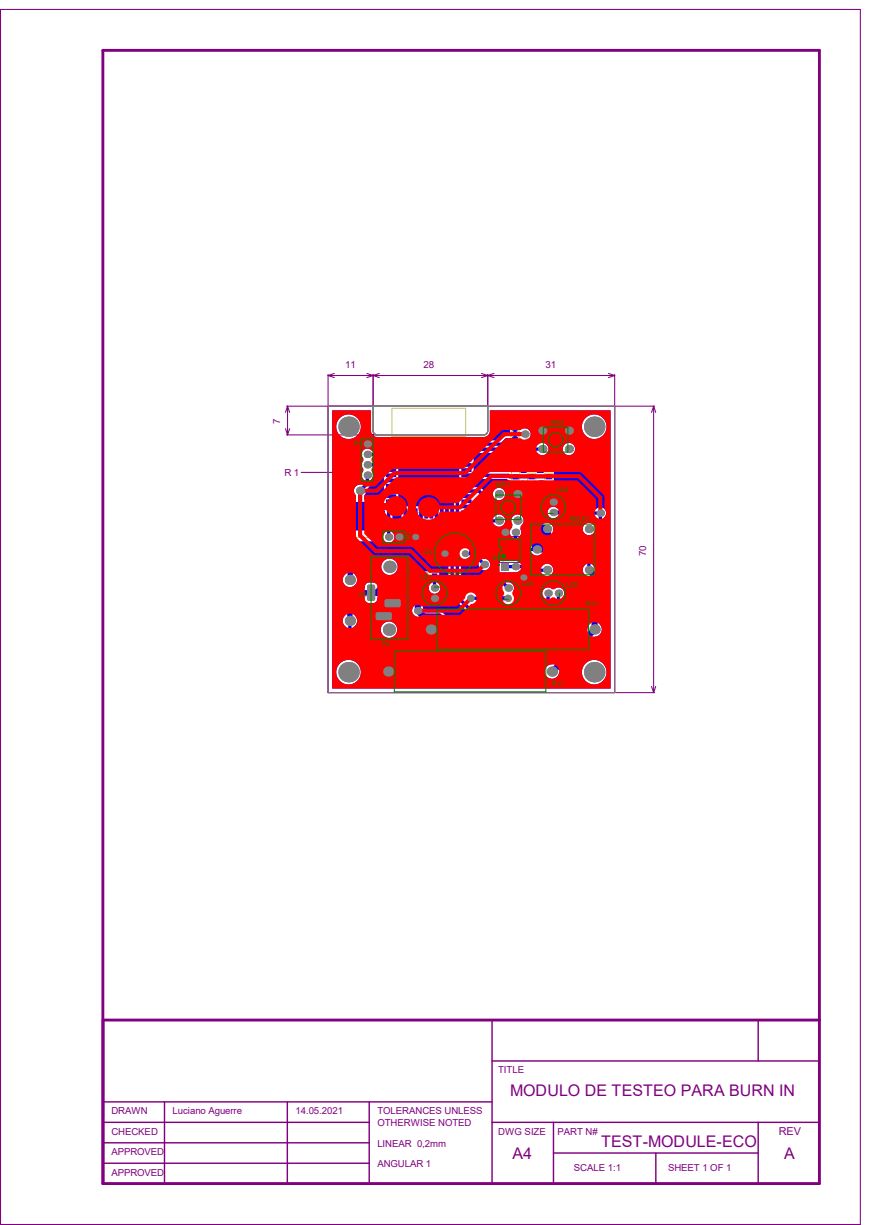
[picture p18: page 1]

TITLE
MODULO DE TESTEO PARA BURN IN

DRAWN | Luciano Aguerre | 14.05.2021 | TOLERANCES UNLESS OTHERWISE NOTED LINEAR 0,2mm ANGULAR 1
CHECKED | | | | DWG SIZE A4 | PART N# TEST-MODULE-ECO | REV A

APPROVED

SCALE 1:1 | SHEET 1 OF 1

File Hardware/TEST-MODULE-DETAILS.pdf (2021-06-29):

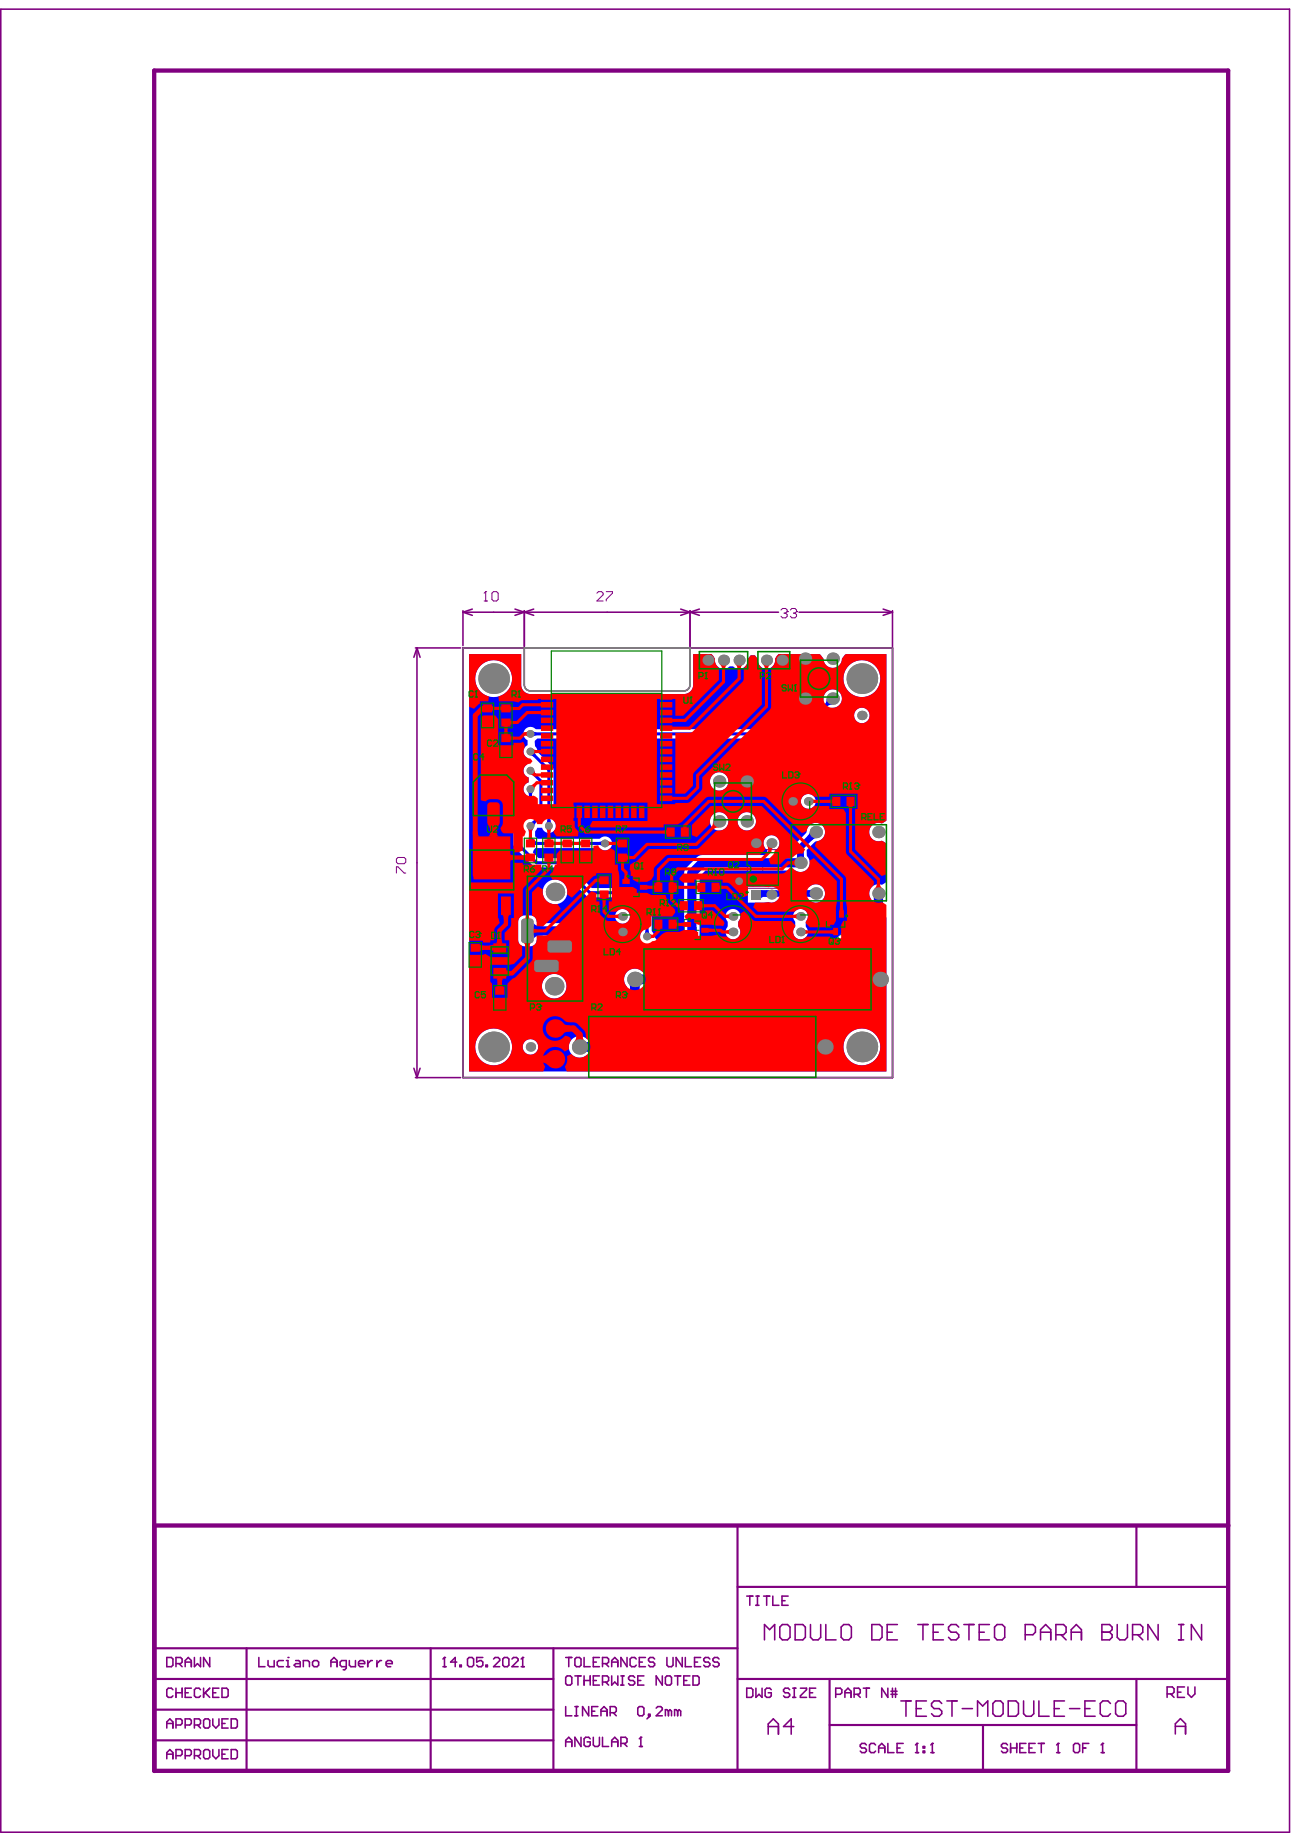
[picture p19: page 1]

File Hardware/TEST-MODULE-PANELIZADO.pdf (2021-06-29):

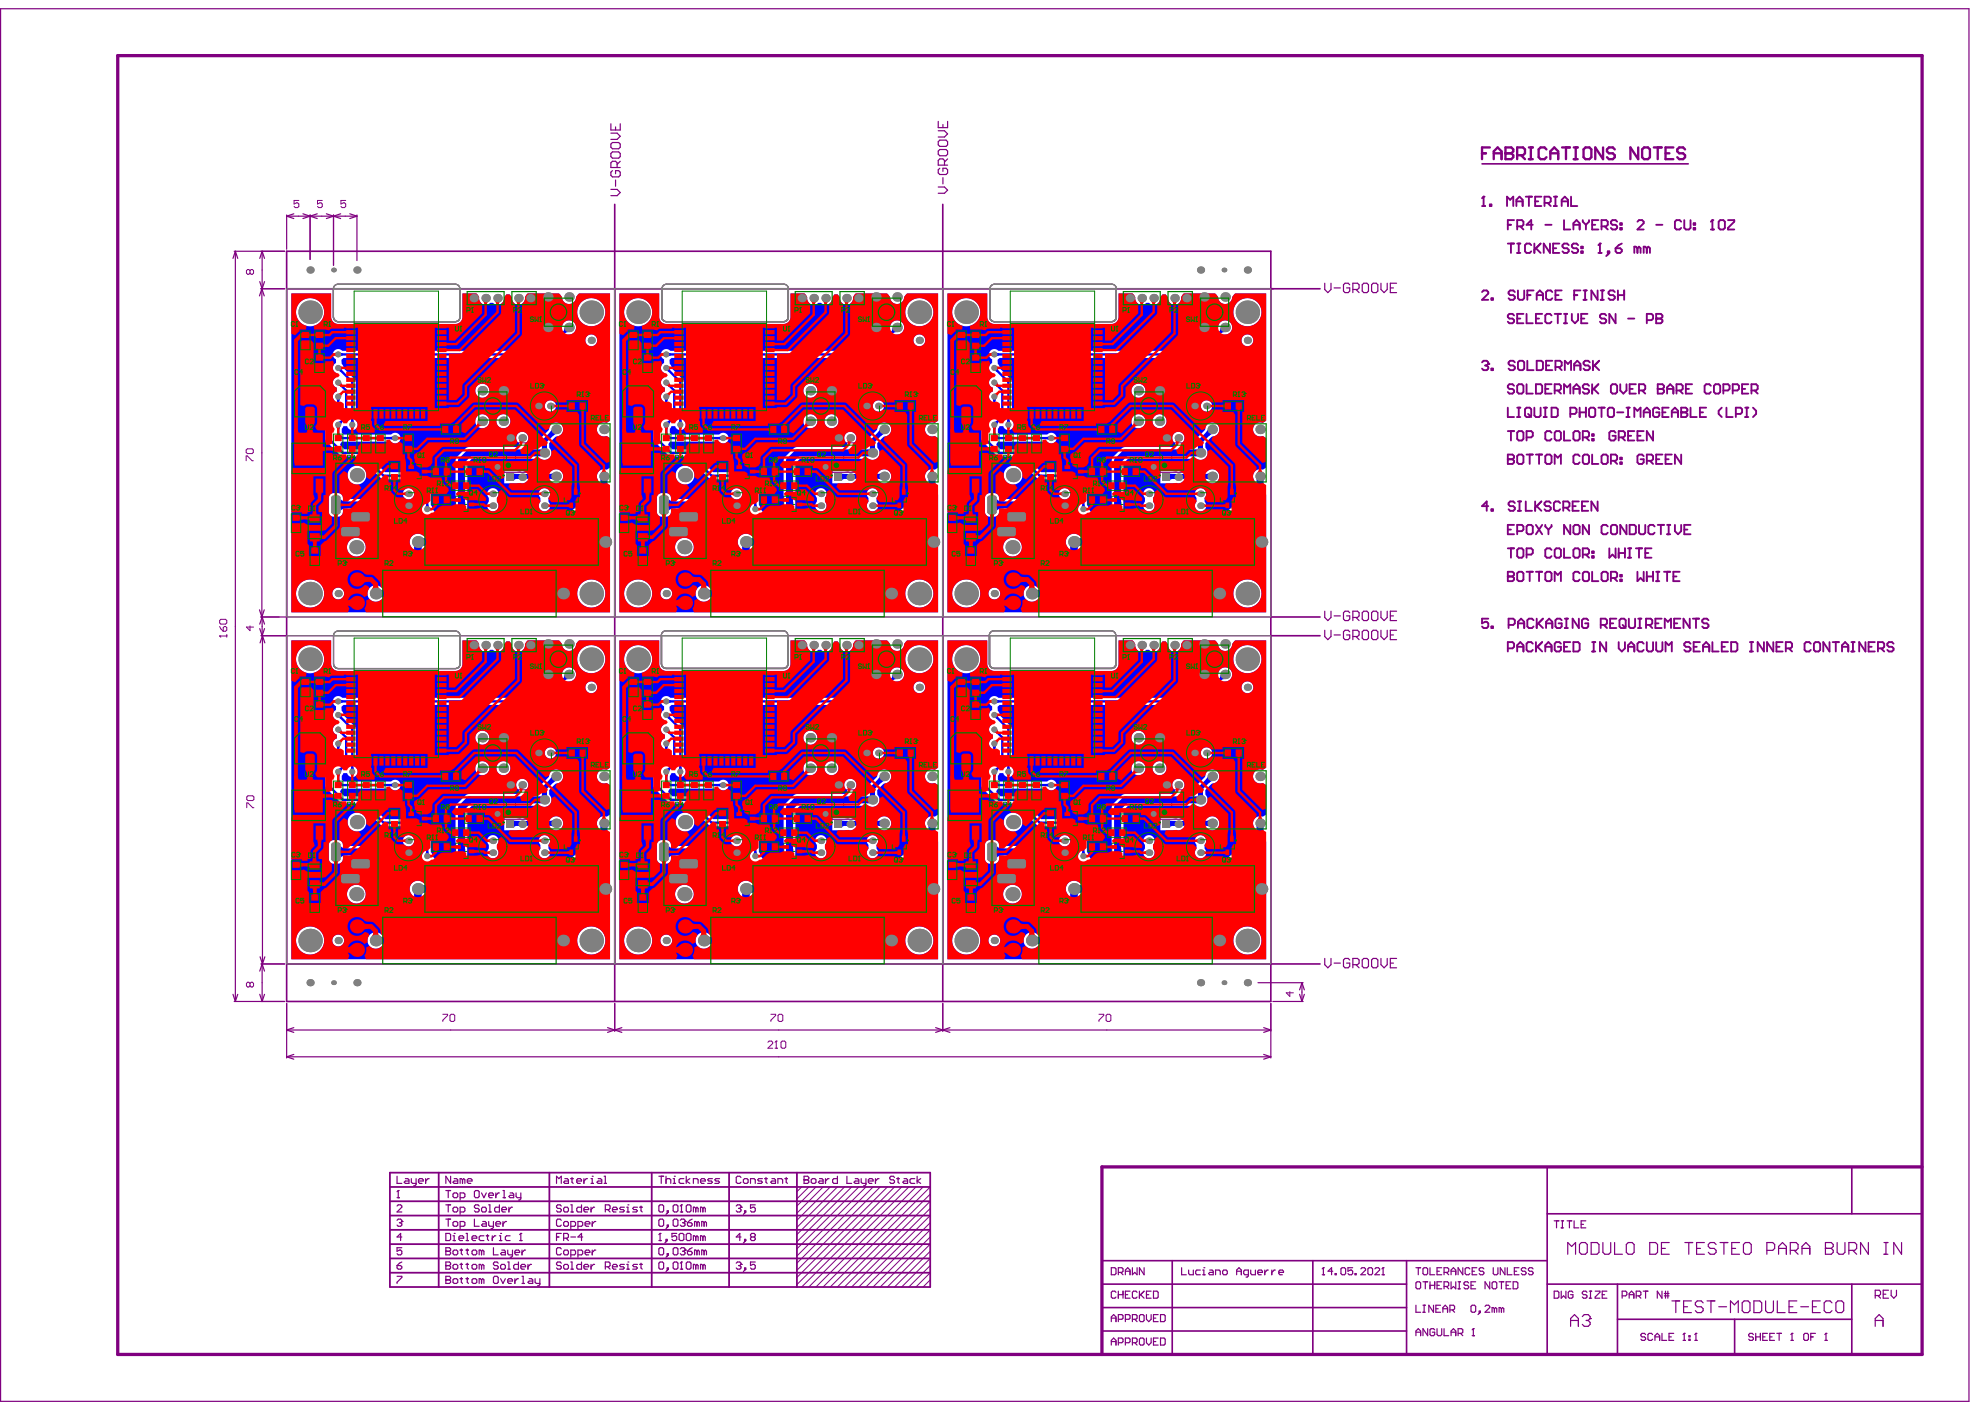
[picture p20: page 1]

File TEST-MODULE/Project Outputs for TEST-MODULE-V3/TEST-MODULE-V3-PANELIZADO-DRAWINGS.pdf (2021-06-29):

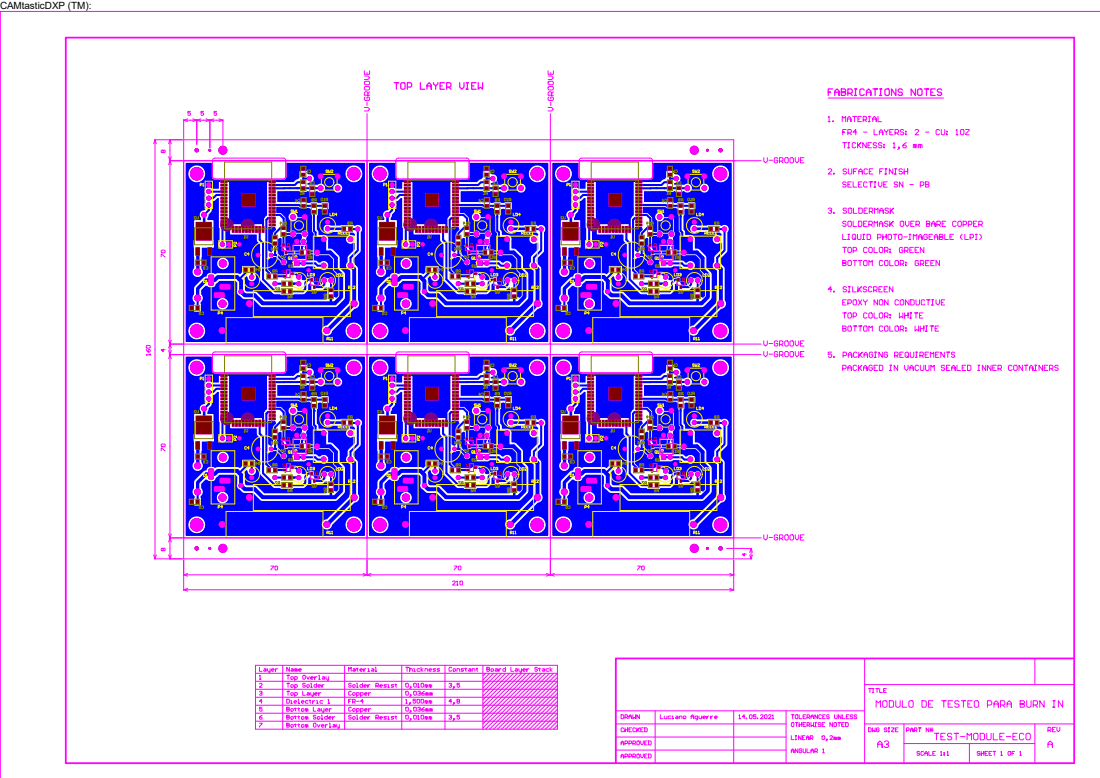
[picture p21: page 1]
CAMtasticDXP (TM):

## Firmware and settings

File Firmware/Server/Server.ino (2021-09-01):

/*******************************************************************************
* Title                 :   Server Module for Burn in Test   
* Filename              :   Server.ino
* Author                :   Luciano Aguerre
* Origin Date           :   13/07/2021
* Version               :   0.1.0
* Compiler              :   Arduino 1.8.13
* Target                :   ESP-WROOM-32
* Notes                 :   None
*******************************************************************************/

/******************************************************************************
* Includes
*******************************************************************************/
#include <WiFi.h>
#include <ESPAsyncWebServer.h>
#include <SPIFFS.h>
#include <WebSocketsServer.h>
#include <ArduinoJson.h>
#include <BLEDevice.h>

#include "config.h"  // Sustituir con datos de vuestra red
#include "API.hpp"
#include "WebSockets.hpp"
#include "Server.hpp"
#include "ESP32_Utils.hpp"
#include "ESP32_Utils_AWS.hpp"
#include "BLE_Utils.hpp"

/******************************************************************************
* Variable Definitions
*******************************************************************************/
//byte   dev_state[100];

/******************************************************************************
* Functions Declarations
*******************************************************************************/
void InitDEVstates(void);

/******************************************************************************
* Setup
*******************************************************************************/
void setup(void)
{
	Serial.begin(115200);
	SPIFFS.begin();
	
	ConnectWiFi_STA();

	InitServer();
	InitWebSockets();
  InitDEVstates();
}

/******************************************************************************
* Loop
* 
*******************************************************************************/
void loop(void)
{
}

/******************************************************************************
* Functions Definitions
*******************************************************************************/
void InitDEVstates(void)
{
  for (byte i = 0; i < 100;i++)
  {
    dev_state[i] = random(0,4);
  }
}
//**** END OF FILE **********************************************************************

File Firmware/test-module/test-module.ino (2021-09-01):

/*******************************************************************************
* Title                 :   Module for Burn in Test   
* Filename              :   test-module.ino
* Author                :   Luciano Aguerre
* Origin Date           :   19/05/2021
* Version               :   0.1.0
* Compiler              :   Arduino 1.8.13
* Target                :   ESP-WROOM-32
* Notes                 :   None
*******************************************************************************/

/******************************************************************************
* Funcional description
* El circuito realiza un ciclado para el burn- test de fuentes de alimentacion
* luego hace un advertizing de los resultados del ensayo a travez de BLE 
* 
*******************************************************************************/

/******************************************************************************
* Includes
*******************************************************************************/
//#include <EEPROM.h>
//#include <rom/rtc.h>
#include <driver/adc.h>
//#include "soc/rtc_cntl_reg.h"

#include "Hardware_Def.h"
#include "Memory.h"
#include "ADC_Utils.hpp"
#include "Test.hpp"
#include "BLE_Functions.hpp"

/******************************************************************************
* Functions Declarations
*******************************************************************************/
void hardware_cfg(void);
void read_adc (void);

/******************************************************************************
* Setup
*******************************************************************************/
void setup()
{
  hardware_cfg();
  Serial.begin(115200); 

  cycle_state = 0;
  Serial.println("Setup terminado");
  
  Serial.println("Secuencia de inicio");
  digitalWrite(LED_RED, HIGH);
  delay(300);
  digitalWrite(LED_RED, LOW);
  digitalWrite(LED_GREEN, HIGH);
  delay(300);
  digitalWrite(LED_GREEN, LOW);

  BLE_setup();
}

/******************************************************************************
* Loop
* 
*******************************************************************************/
void loop() 
{
     test_procedure();
     delay(2000);
}

/******************************************************************************
* Functions Definitions
*******************************************************************************/
void hardware_cfg (void)
{
  pinMode(LED_RED, OUTPUT);
  pinMode(LED_GREEN, OUTPUT);
  pinMode(ACT, OUTPUT);
  pinMode(VIN, INPUT);
  
  digitalWrite(LED_RED,LOW);
  digitalWrite(LED_GREEN,LOW);
  digitalWrite(ACT,LOW);
  
  adc1_config_width(ADC_WIDTH_BIT_11);
  adc1_config_channel_atten(ADC1_CHANNEL_4,ADC_ATTEN_DB_11);
}


//**** END OF FILE **********************************************************************

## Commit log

2021-04-23 commit inicial
    [1243987472.iam, AMS1173.3V_v1.ipt, AXIAL-POWER.ipt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]
2021-04-28 files cleaned up & drills added
    [MAIN-BOARD.SchDoc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]
2021-05-21 firmware updated - One board version
    [1243987472.iam, 1N4007DiodeBody.ipt, 1N4007DiodeLeg.ipt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]
2021-05-31 Firmware update
    [TEST-MODULE-V2.SchDoc]
2021-06-29 Hardware final version
    [1N4007DiodeBody.ipt, 1N4007DiodeLeg.ipt, AXIAL-POWER-10W.ipt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]
2021-07-14 Server firmware added - JSON script ok
    [TEST-MODULE-V3.xls, TEST-MODULE.PrjPcb, TEST-MODULE.SchDoc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]
